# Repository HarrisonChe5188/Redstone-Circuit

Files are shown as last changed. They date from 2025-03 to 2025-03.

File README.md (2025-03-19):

# Redstone-Rewired
A passion project of bringing a Minecraft redstone circuit to life for Boston University's Lutron Lighting Innovation Competition. We also won first place!

Project Overview

This project brings Minecraft redstone circuits to life using an Arduino, basic electronics, and snap-on wire connectors to create a modular system. The components replicate Minecraft mechanics, including:

Redstone Torch 🔥
Redstone Lamp 💡
Lever ⚡
Piston (with Arduino-controlled Servo) 🏗
Wooden Slab 🪵

Each component connects using modular snap-on wire connectors, allowing easy assembly and reconfiguration—just like placing blocks in Minecraft!
Check out README.pdf for further details

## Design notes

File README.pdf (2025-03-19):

# Modular Redstone Circuit with Arduino and Snap-On Connectors

Nick Gerasev, Nick Lin, Ezan Khan, Harrison Che

(Earned 1st Place of the Lutron Lighting Innovation Competition)

## 1 The Gang

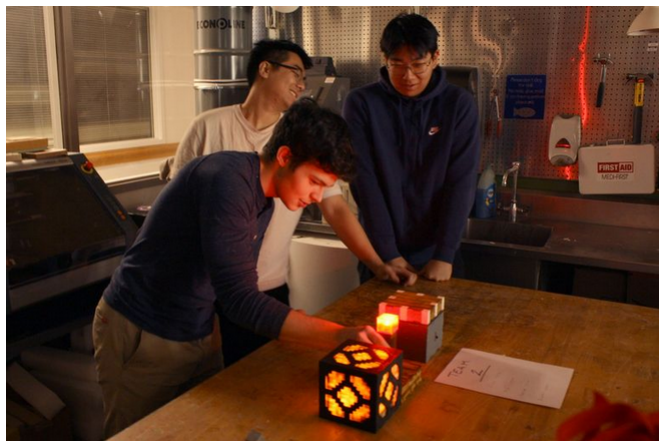
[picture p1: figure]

From left to right: Nick, Nick, Harrison, and Ezan (in spirit).

## 2 Project Overview

This project brings Minecraft redstone circuits to life using an Arduino, basic electronics, and snap-on wire connectors to create a modular system. The components replicate Minecraft mechanics, including:

- Redstone Torch
- Redstone Lamp
- Lever

1

- Piston (with Arduino-controlled Servo)
- Wooden Slab

Each component connects using modular snap-on wire connectors, allowing easy assembly and reconfiguration—just like placing blocks in Minecraft!

## 3 How It Works

- The lever toggles the circuit on and off.
- The redstone torch provides continuous power when placed.
- The redstone lamp lights up when powered.
- The piston is controlled via an Arduino and servo motor, moving when the circuit is powered.
- Snap-on wire connectors allow modular and easy circuit assembly.

## 4 Hardware & Materials

- Arduino (Uno/Nano/etc.)
- Servo Motor (for piston movement)
- LEDs (for redstone torch & lamp)
- Resistors
- Push Button / Toggle Switch (for lever)
- Wood/Plastic pieces (for modular design)
- Snap-on wire connectors
- Jumper Wires & Soldering Kit

## 5 Code & Circuit Setup

1. Upload the provided Arduino sketch to control the piston.
2. Connect the components according to the circuit diagram (see below).
3. Use snap-on connectors to assemble and test different redstone circuits.

2

## 6 Circuit Diagram

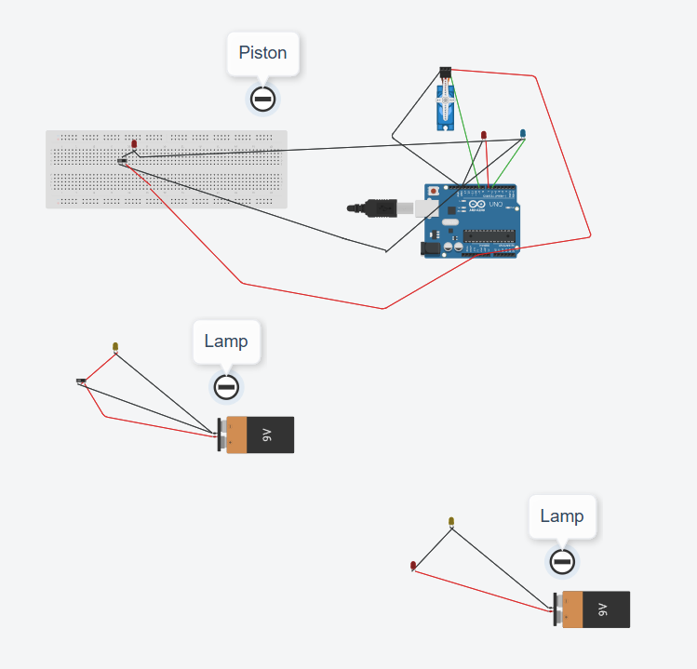
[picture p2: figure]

## 7 Project Images

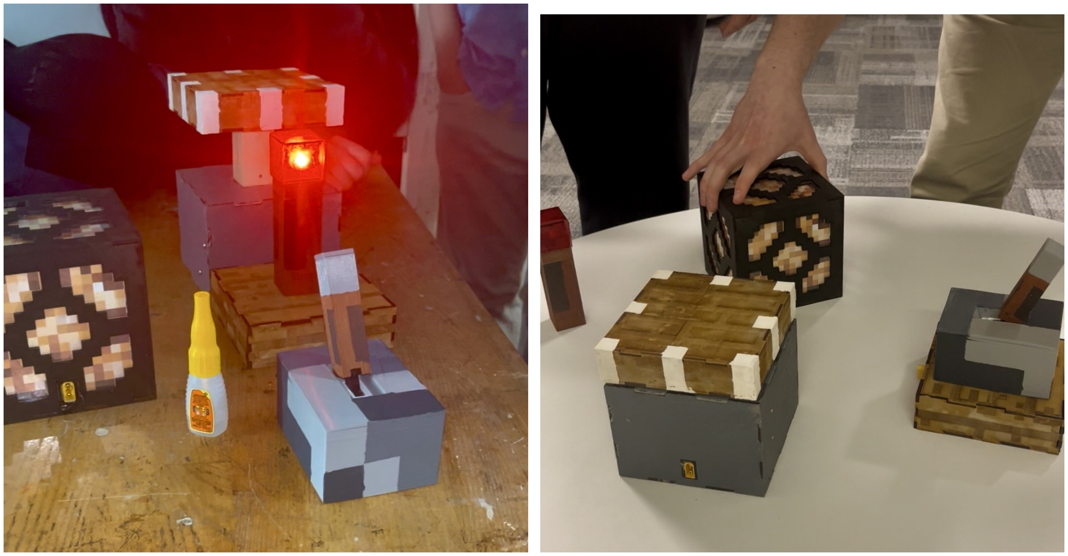
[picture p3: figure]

3

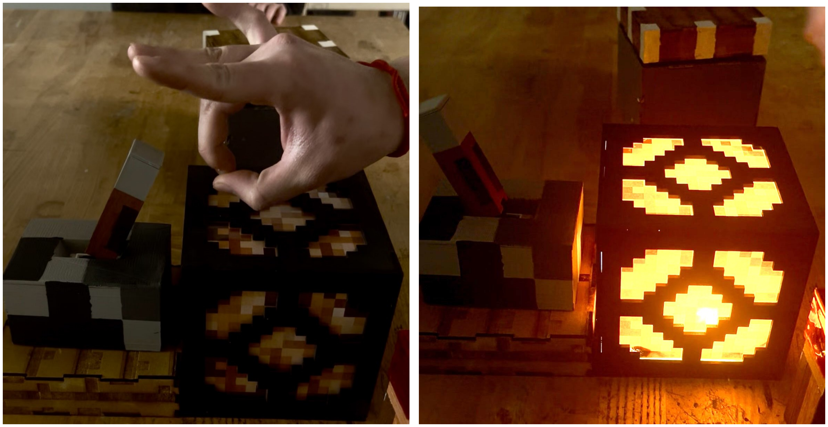
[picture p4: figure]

## 8 Future Improvements

- Add more redstone components (e.g., repeaters, comparators)
- Improve modularity with 3D-printed casings
- Integrate with a larger Minecraft-inspired automation system

4

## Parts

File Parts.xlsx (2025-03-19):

ORDERED
Item | Brand & Link | Cost | Comment | Budget | $50.00
Servo | hiwonder 20kg (https://a.co/d/fIgypI5) | $13.98 |  | Spent | $49.31
Switch (for lever) | GE Lighting (https://a.co/d/9RvSF5E) | $3.88 |  | Remaining | $0.69
XT60 Connectors (x10) | MCIGICM (https://a.co/d/6WLzdpj) | $7.99
8x AA battery holder (x2) | SDTC (https://a.co/d/9OlMkR2) | $8.49 | need 16 AA batteries
12V 5W 500 Lumen LED (x2) | PYRJIN (https://a.co/d/g0RK5KB) | $6.99
1W 2.4V 350mA red LEDs (x20) | LedWekei (https://a.co/d/958zADE) | $7.98
 |  |  |  | Switch | could cad replica of the plastic part with our own extension and replace it, or just screw on our own extension to the plastic part
OPTIONS
8x AA battery holder (x2) | QTEATAK (https://a.co/d/4oF4RvY) | $6.99
1W 2.4V 350mA red LEDs (x20) | LedWekei (https://a.co/d/958zADE) | $7.98 | can go over budget for this
AA 1.5V batteries (x20) | Amazon (https://a.co/d/4guizxU) | $10.53
AA 1.5V batteries (x20) | Energizer (https://a.co/d/cXEJw0G) | $13.66
AA 1.5V batteries (x12) | Voniko (https://a.co/d/crO3REi) | $6.99
AA 1.5V batteries (x36) | Voniko (https://a.co/d/bhzOJ9x) | $12.39
AA 1.5V batteries (x24) | Duracell (https://a.co/d/6fPRhtN) | $18.64
Other
USB | usb (https://www.googleadservices.com/pagead/aclk?ai=DChcSEwi-pISMuqGLAxUeYUcBHSK6F-0YABAFGgJxdQ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)
Super Glue | EPIC
Soldering | SILAB
LEDs
Super LED for Lamp
Wires
Batteries (x2)
Arduino | Ezan | $0.00
Aesthetic Stuff
Lasercuting wood | EPIC | $0.00
3d Printing Filament | EPIC, SILAB? | $0.00
Fabric for designs
Print out design on paper?
Paint? | Some silab, some purchase. By color

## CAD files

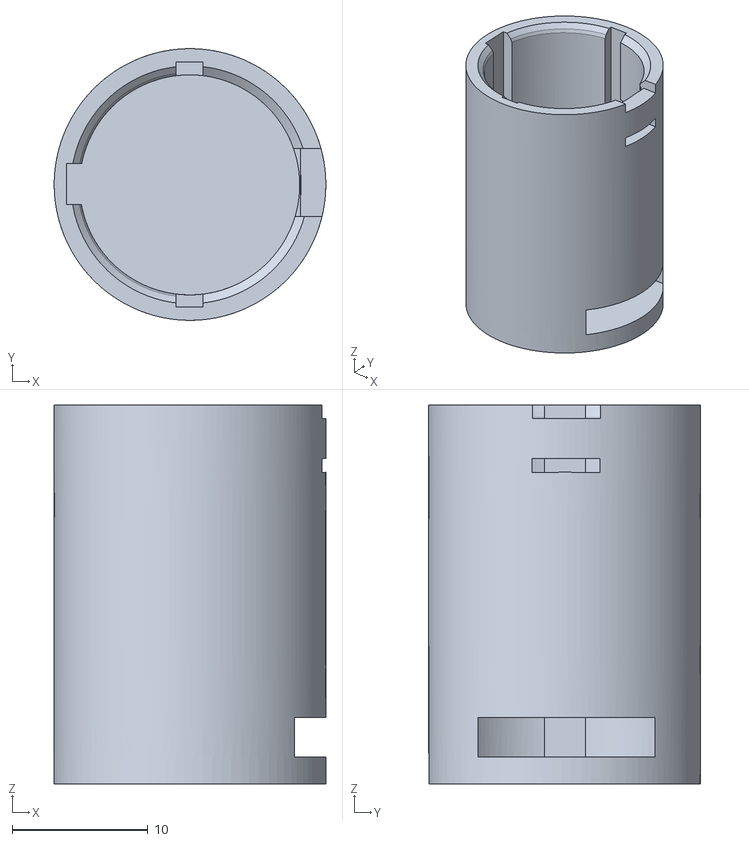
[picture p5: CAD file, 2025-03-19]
connectors/BAY15 connector.STL
20.0 x 20.0 x 27.9

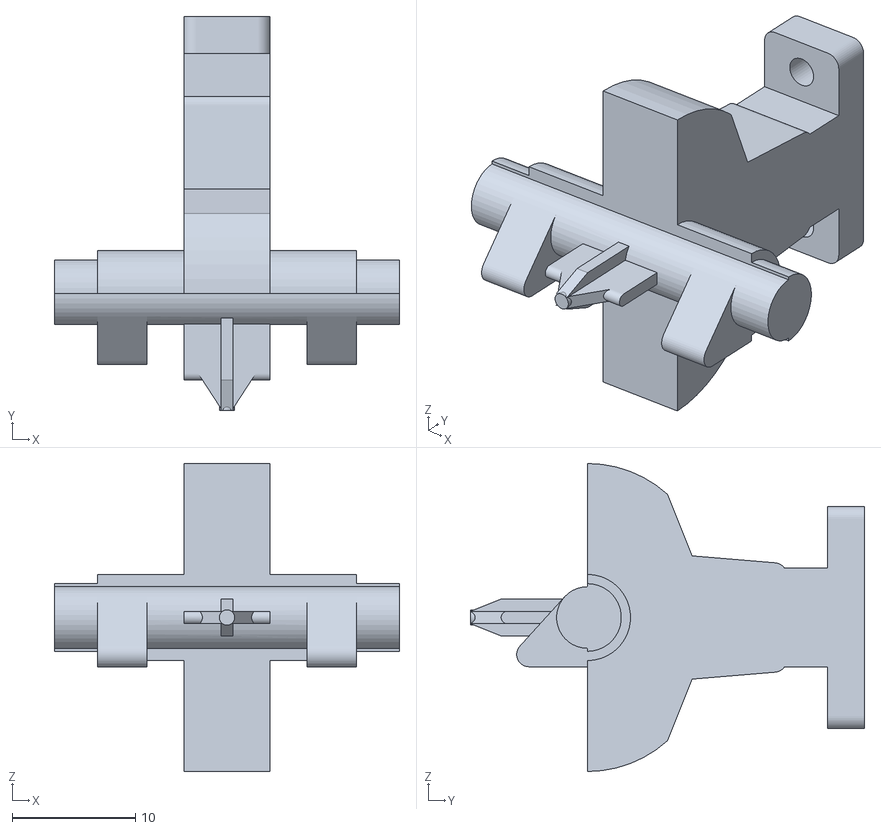
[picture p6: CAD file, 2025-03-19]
lever/LutronSwitch.STL
28.0 x 32.0 x 25.0

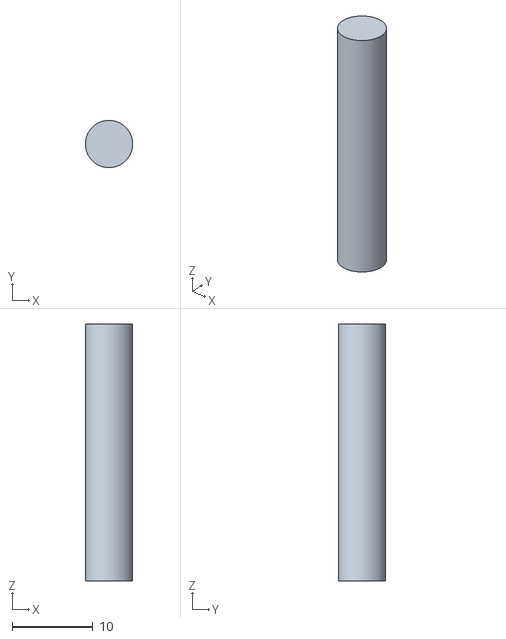
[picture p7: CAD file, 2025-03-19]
piston/STICK.stl
5.84 x 5.83 x 31.8

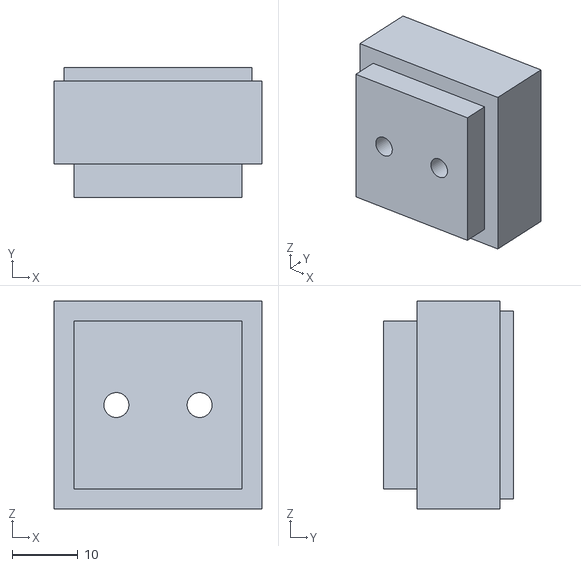
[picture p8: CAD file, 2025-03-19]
torch/torchtop.STL
31.8 x 19.8 x 31.8

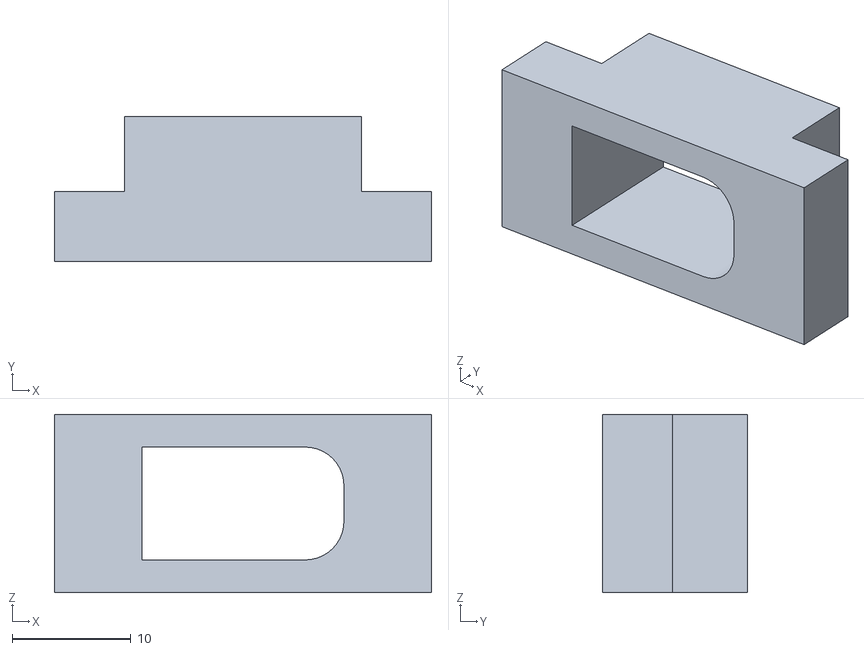
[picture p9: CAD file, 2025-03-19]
connectors/connectormalelever.STL
31.8 x 12.2 x 15.0

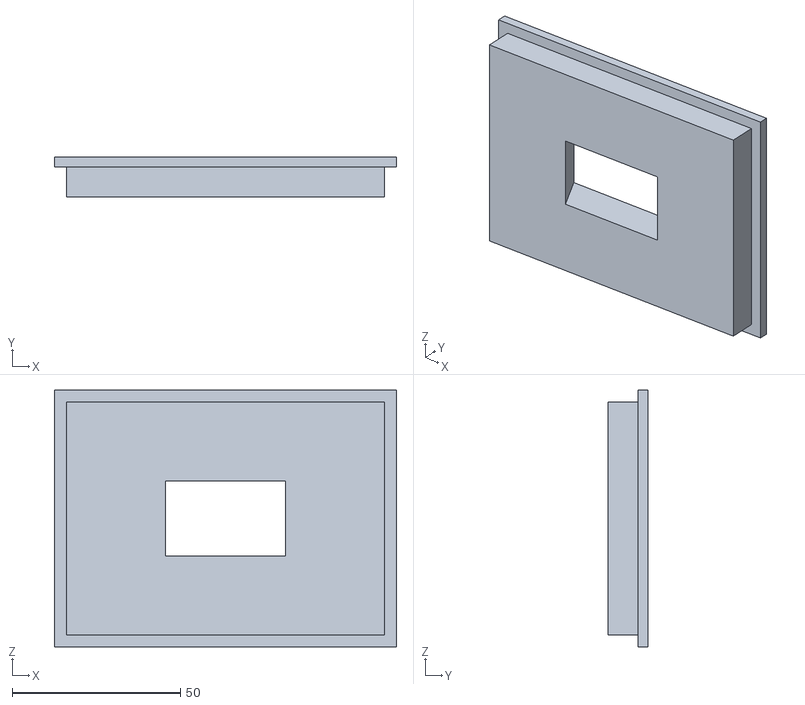
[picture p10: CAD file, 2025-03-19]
lever/leverboxtop.STL
101.6 x 12.0 x 76.2

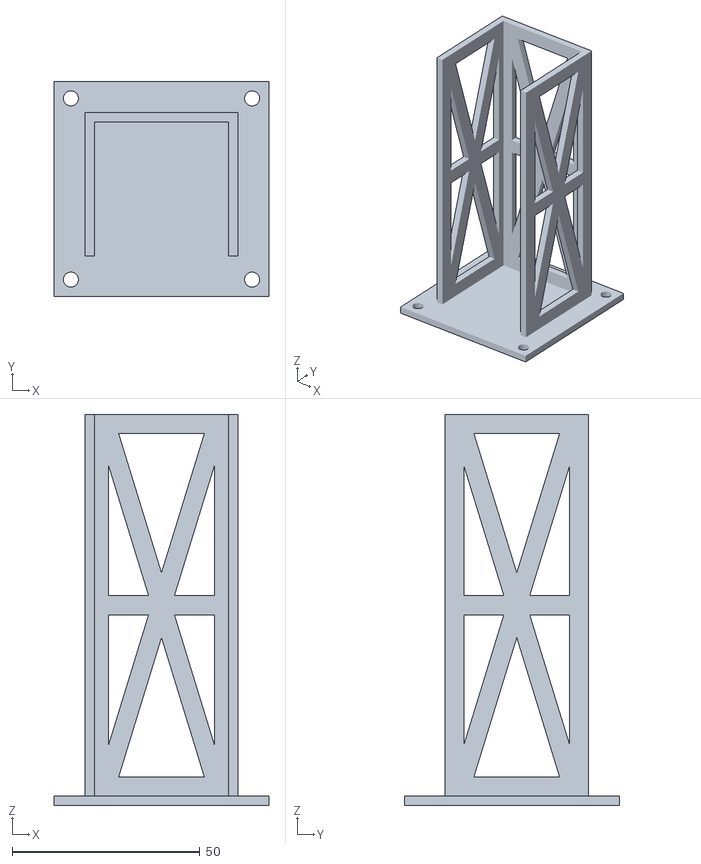
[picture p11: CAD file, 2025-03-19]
piston/piston restrainer.stl
57.1 x 57.1 x 104.1

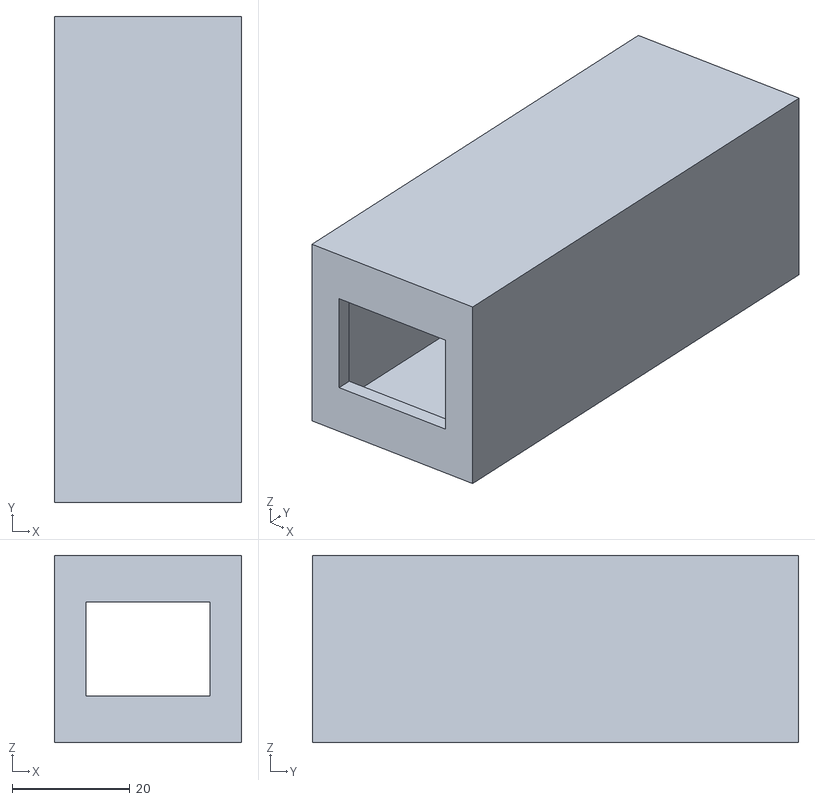
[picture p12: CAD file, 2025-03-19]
torch/torchbox.STL
31.8 x 82.5 x 31.8

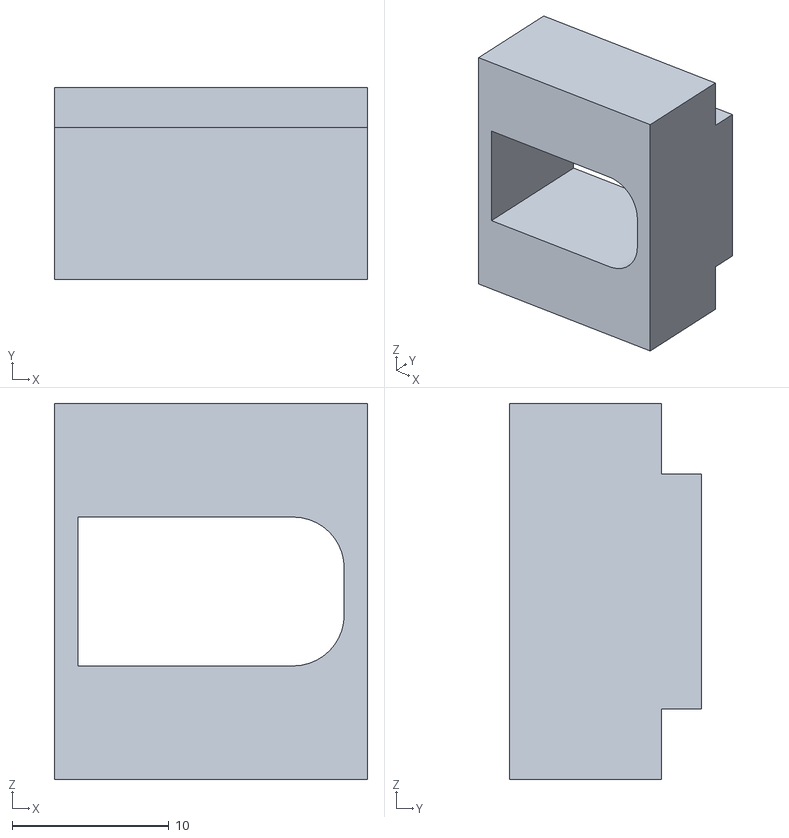
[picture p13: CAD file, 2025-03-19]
connectors/connectortorch.STL
20.0 x 12.2 x 24.0

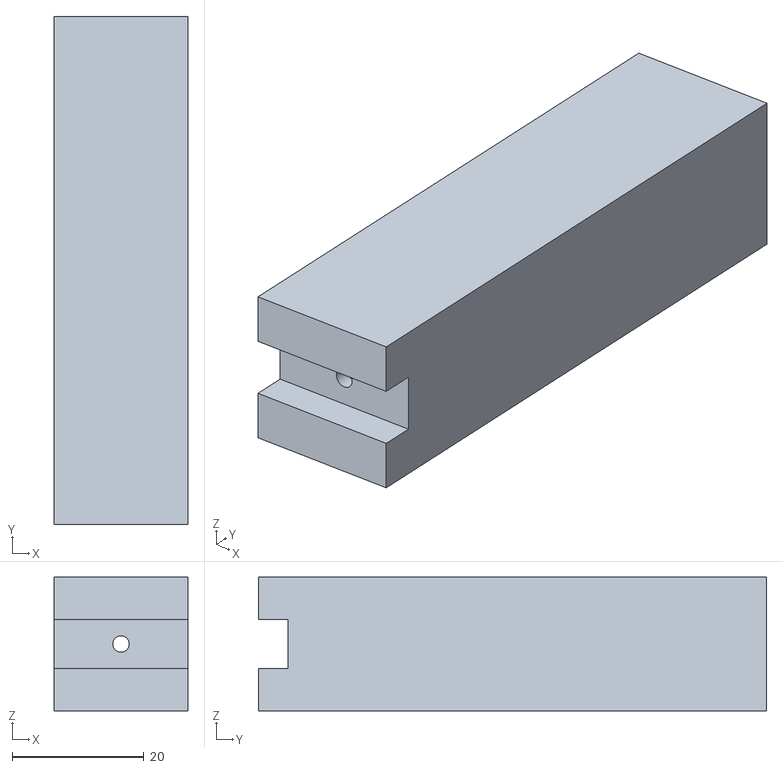
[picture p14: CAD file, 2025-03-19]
lever/leverbar.STL
20.3 x 77.2 x 20.3

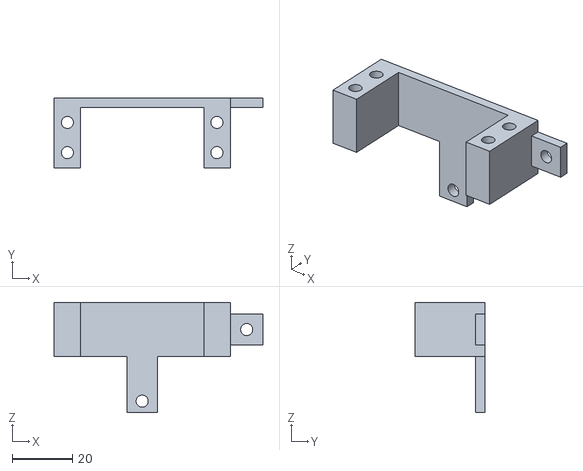
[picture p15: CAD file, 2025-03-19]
piston/bracket.stl
69.2 x 23.0 x 36.5

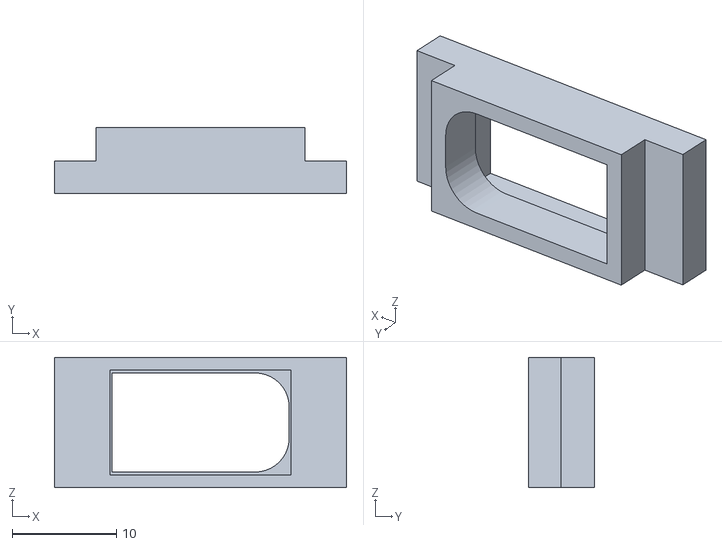
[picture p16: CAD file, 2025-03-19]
connectors/connectorfemale - femaleconnector.STL
28.0 x 6.30 x 12.5

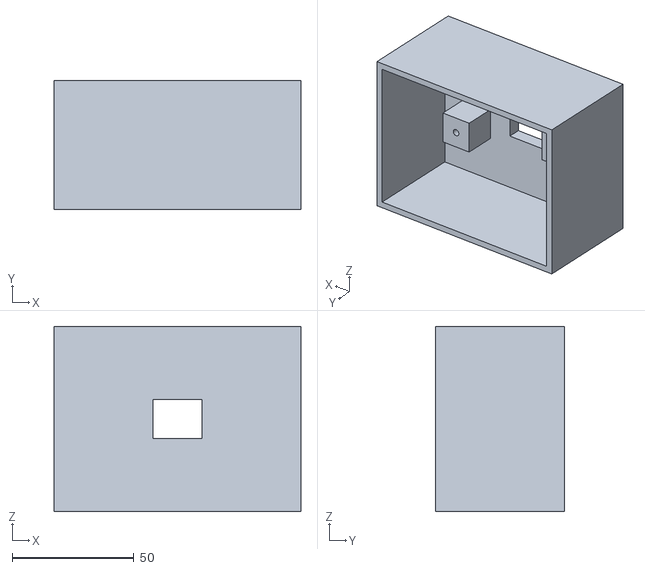
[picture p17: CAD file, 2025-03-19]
lever/leverbox.STL
101.6 x 53.0 x 76.2

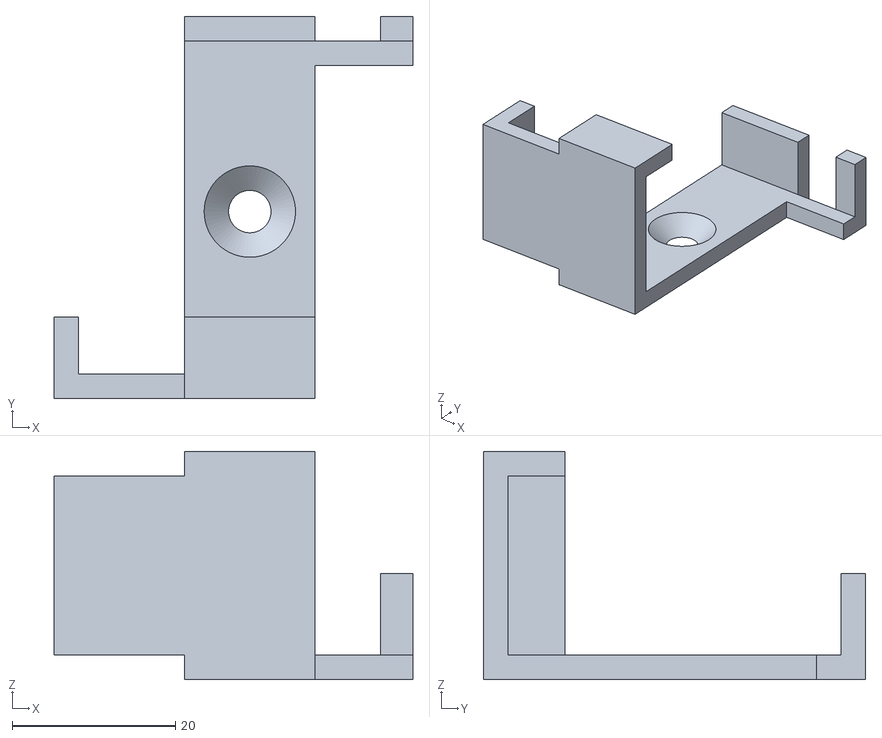
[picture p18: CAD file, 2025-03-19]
piston/servo holder.stl
44.0 x 46.8 x 28.0

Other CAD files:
connectors/lamppistonconnector.STL
lever/levercap.STL
piston/linkage.stl

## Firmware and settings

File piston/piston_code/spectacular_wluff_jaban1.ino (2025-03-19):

#include <Servo.h>  

Servo myservo;  // create servo object to control a servo
int pos = 0;    // variable to store the servo position
unsigned long startMillis;  // stores the time when the motion starts
bool buttonState = false;  // button state (pressed or not pressed)
bool lastButtonState = false;  // previous button state

void setup() {
  myservo.attach(9);      // Attaches the servo to pin 9
  Serial.begin(9600);     // Starts serial communication at 9600 baud
  pinMode(6, INPUT);      // Set pin 6 as input for the button
}

void loop() {
  buttonState = digitalRead(6);  // Read the current state of the button

  // If the button is pressed and it wasn't pressed before, start moving the servo
  if (buttonState == HIGH && lastButtonState == LOW) {
    startMillis = millis();  // Record the start time when button is pressed
    while (buttonState == HIGH) {  // Continue while button is still pressed
      unsigned long currentMillis = millis();  // Get current time
      int elapsedTime = currentMillis - startMillis;  // Calculate elapsed time

      if (elapsedTime <= 250) {
        pos = map(elapsedTime, 0, 250, 0, 63);  // Map the time to servo position
        myservo.write(pos);  // Move the servo to the calculated position
      } else {
        break;  // Exit the loop after 250ms
      }
      buttonState = digitalRead(6);  // Check if button state has changed
    }
  }

  // If the button is not pressed, move the servo back to 0 degrees
  if (buttonState == LOW && lastButtonState == HIGH) {
    startMillis = millis();  // Record the start time when button is released
    while (buttonState == LOW) {  // Continue while button is still not pressed
      unsigned long currentMillis = millis();  // Get current time
      int elapsedTime = currentMillis - startMillis;  // Calculate elapsed time

      if (elapsedTime <= 250) {
        pos = map(elapsedTime, 0, 250, 63, 0);  // Map the time to servo position
        myservo.write(pos);  // Move the servo to the calculated position
      } else {
        break;  // Exit the loop after 250ms
      }
      buttonState = digitalRead(6);  // Check if button state has changed
    }
  }

  // Update lastButtonState to the current button state
  lastButtonState = buttonState;
}
